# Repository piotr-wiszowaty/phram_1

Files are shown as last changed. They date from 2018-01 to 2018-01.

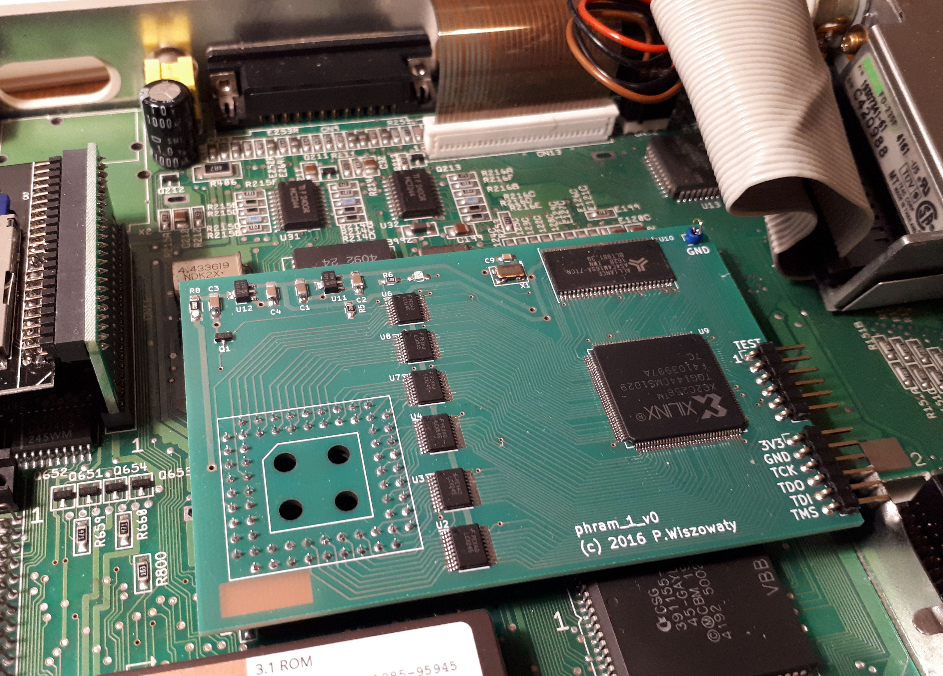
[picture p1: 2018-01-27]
prod/phram_1.jpg

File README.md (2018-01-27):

phram\_1
========

phram\_1 is a Commodore Amiga A600 extension - 8 MB of fast RAM.

Features :
----------

* based on modern parts (CoolRunner CPLD, SDRAM)
* PCMCIA-friendly: holding `reset` for more than 3 seconds turns off high 4 MB
* current consumption around 110 mA
* speedup relative to stock A600: 33 % (by SysInfo)
* successfully tested with CheckMem and MemCheck 1.2 (both available
  on [Aminet](http://aminet.net)).

Sources
-------

`cpld/` - MMU design files (Xilinx ISE 14.7)

`pcb/`  - PCB design files (KiCAD, built 2017-11-24 revision a01d81e4b)

`prod/` - JED, Gerbers and a photo of the expansion; the current PCB
          has some tweaks compared with the device on the photo

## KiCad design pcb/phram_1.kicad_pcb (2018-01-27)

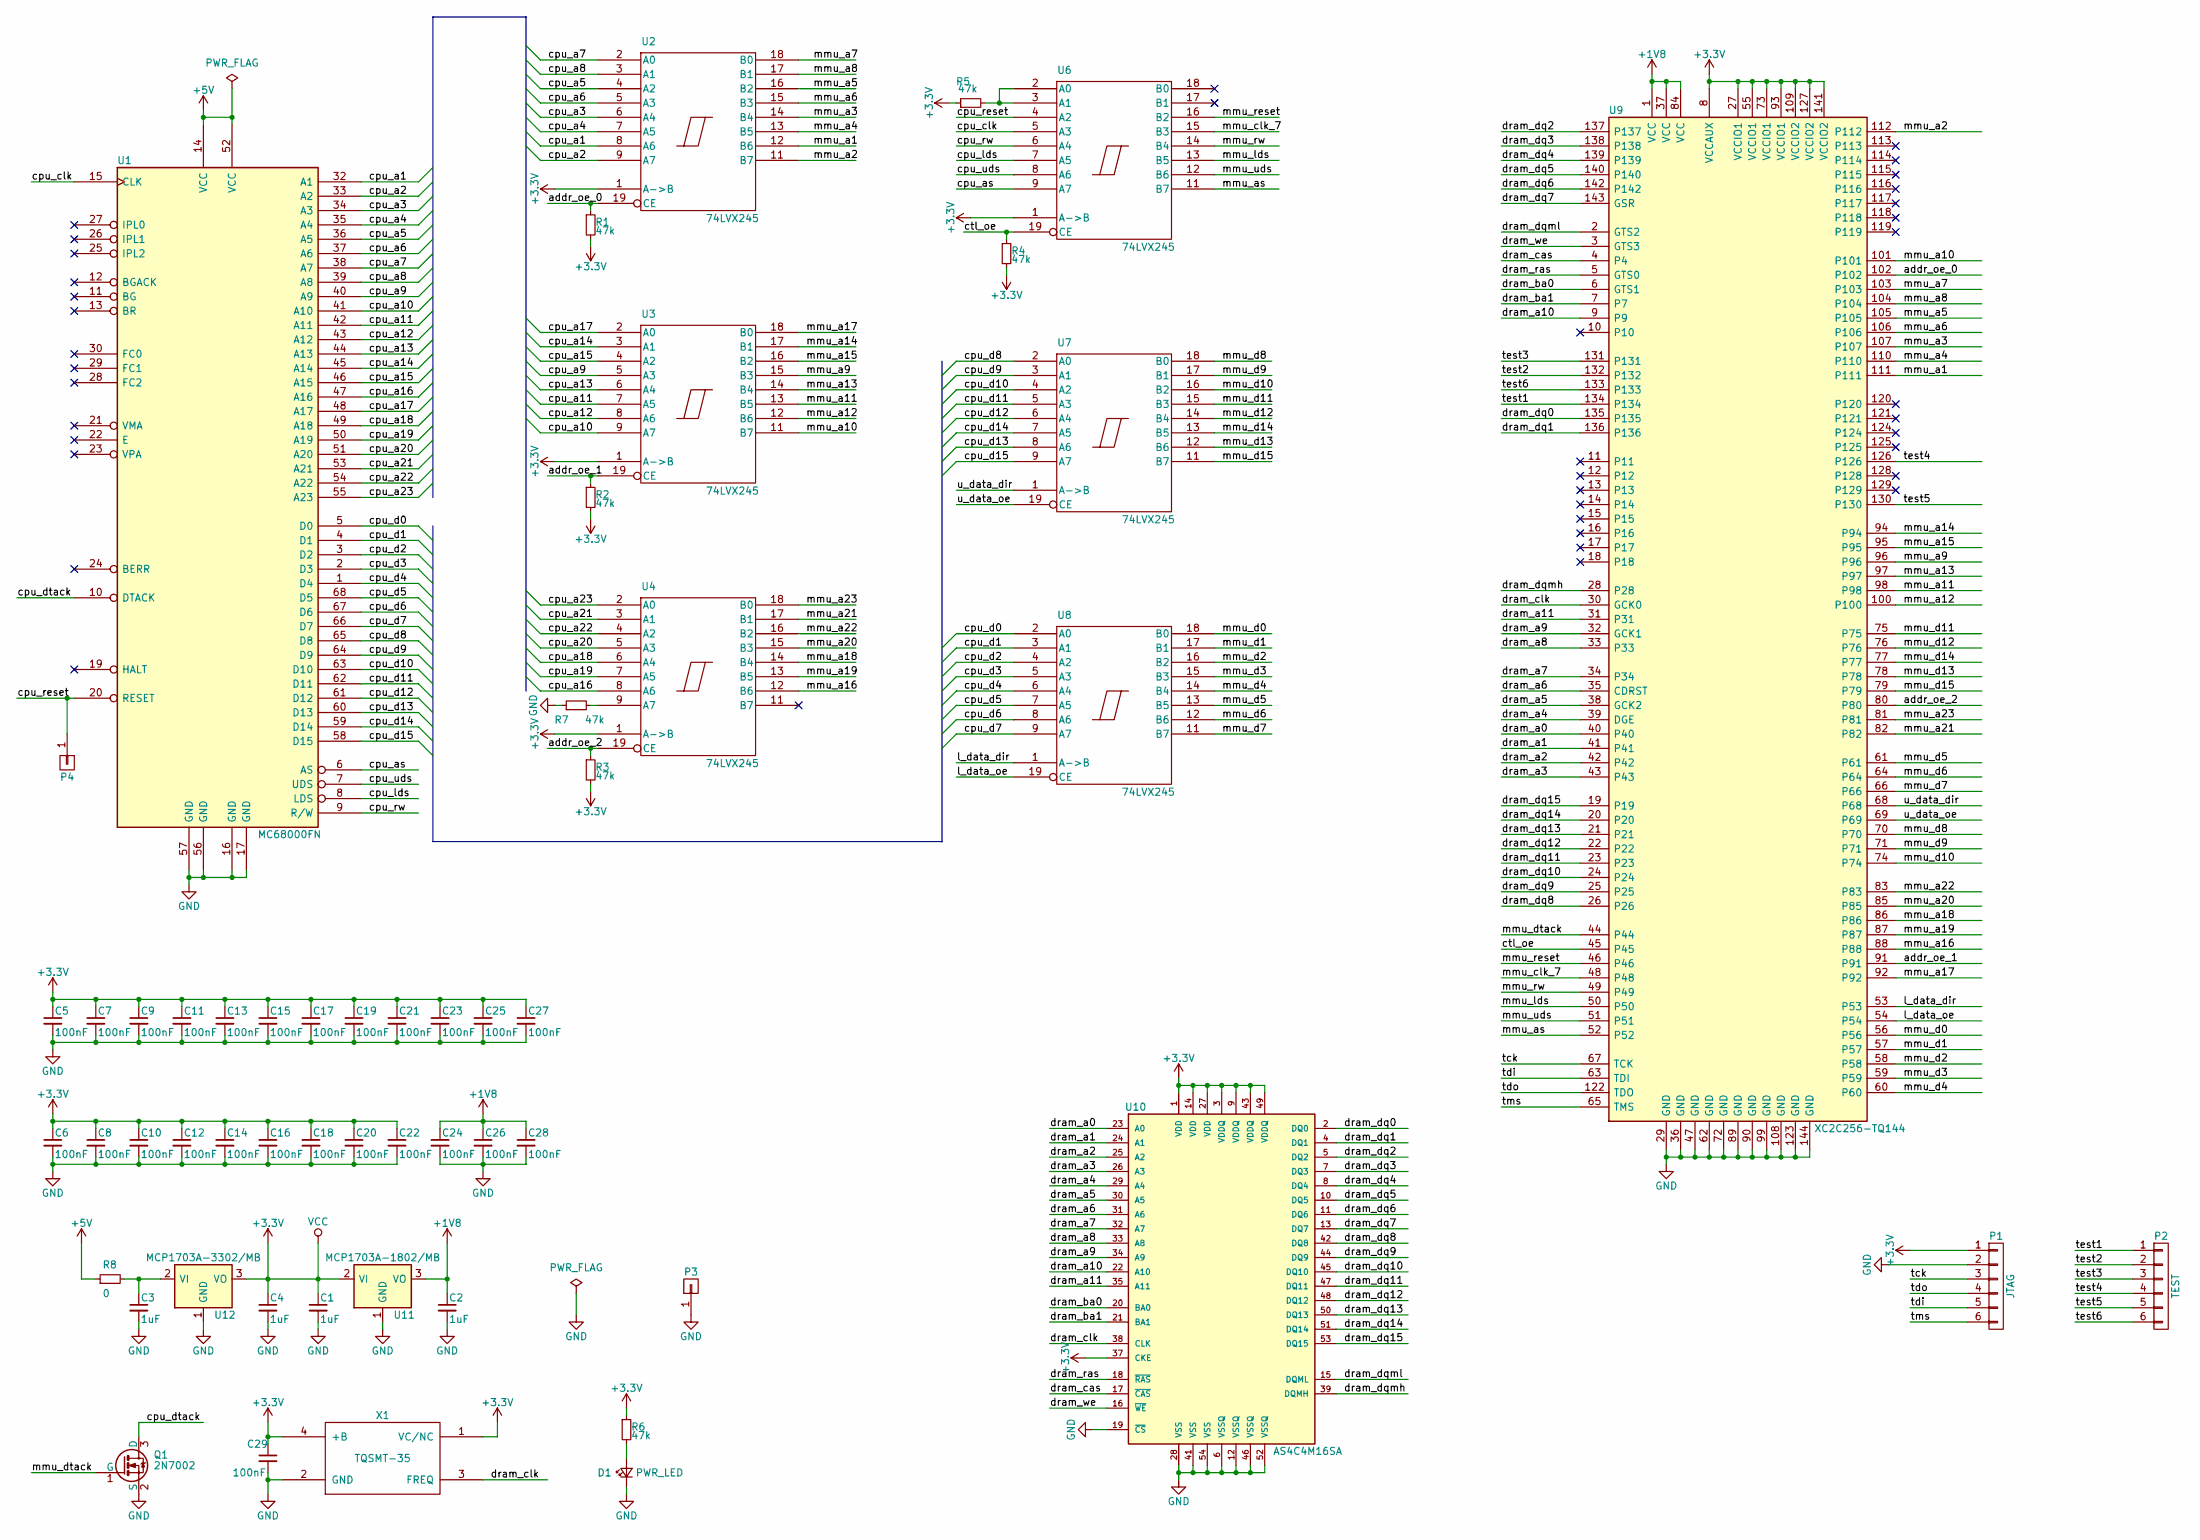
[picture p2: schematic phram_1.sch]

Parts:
C1, C2, C3, C4: 1uF; C_1206_HandSoldering
C5, C6, C7, C8, C9, C10, C11, C12, C13, C14, C15, C16, C17, C18, C19, C20, C21, C22, C23, C24, C25, C26, C27, C28, C29: 100nF; C_0805_HandSoldering
D1: PWR_LED; R_0805_HandSoldering
P1: JTAG; Pin_Header_Angled_1x06
P2: TEST; Pin_Header_Angled_1x06
P3, P4: CONN_01X01; Pin_Header_Straight_1x01
Q1: 2N7002; SOT-23
R1, R2, R3, R4, R5, R6, R7: 47k; R_0805_HandSoldering
R8: 0; R_1206_HandSoldering
U1: MC68000FN; PLCC68-upsidedown
U2, U3, U4, U6, U7, U8: 74LVX245; TSSOP-20_4.4x6.5mm_Pitch0.65mm
U9: XC2C256-TQ144; TQFP-144_20x20mm_Pitch0.5mm
U10: AS4C4M16SA; TSOP-II-54_22.22x10.16mm_Pitch0.8mm
U11: MCP1703A-1802/MB; SOT89-3_Housing
U12: MCP1703A-3302/MB; SOT89-3_Housing
X1: TQSMT-35; IS92

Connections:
+1V8: C2.1, C24.1, C26.1, C28.1, U9.1 (VCC), U9.37 (VCC), U9.84 (VCC), U11.3 (VO)
+3V3: C1.1, C4.1, C5.1, C6.1, C7.1, C8.1, C9.1, C10.1, C11.1, C12.1, C13.1, C14.1, C15.1, C16.1, C17.1, C18.1, C19.1, C20.1, C21.1, C22.1, C23.1, C25.1, C27.1, C29.1, P1.1, R1.2, R2.2, R3.2, R4.2, R5.1, R6.1, U2.1 (A->B), U2.20 (VCC), U3.1 (A->B), U3.20 (VCC), U4.1 (A->B), U4.20 (VCC), U6.1 (A->B), U6.20 (VCC), U7.20 (VCC), U8.20 (VCC), U9.8 (VCCAUX), U9.27 (VCCIO1), U9.55 (VCCIO1), U9.73 (VCCIO1), U9.93 (VCCIO1), U9.109 (VCCIO2), U9.127 (VCCIO2), U9.141 (VCCIO2), U10.1 (VDD), U10.3 (VDDQ), U10.9 (VDDQ), U10.14 (VDD), U10.27 (VDD), U10.37 (CKE), U10.43 (VDDQ), U10.49 (VDDQ), U11.2 (VI), U12.3 (VO), X1.1 (VC/NC), X1.4 (+B)
+5V: R8.1, U1.14 (VCC), U1.52 (VCC)
/addr_oe_0: R1.1, U2.19 (CE), U9.102
/addr_oe_1: R2.1, U3.19 (CE), U9.91
/addr_oe_2: R3.1, U4.19 (CE), U9.80
/cpu_a1: U1.32 (A1), U2.8 (A6)
/cpu_a2: U1.33 (A2), U2.9 (A7)
/cpu_a3: U1.34 (A3), U2.6 (A4)
/cpu_a4: U1.35 (A4), U2.7 (A5)
/cpu_a5: U1.36 (A5), U2.4 (A2)
/cpu_a6: U1.37 (A6), U2.5 (A3)
/cpu_a7: U1.38 (A7), U2.2 (A0)
/cpu_a8: U1.39 (A8), U2.3 (A1)
/cpu_a9: U1.40 (A9), U3.5 (A3)
/cpu_a10: U1.41 (A10), U3.9 (A7)
/cpu_a11: U1.42 (A11), U3.7 (A5)
/cpu_a12: U1.43 (A12), U3.8 (A6)
/cpu_a13: U1.44 (A13), U3.6 (A4)
/cpu_a14: U1.45 (A14), U3.3 (A1)
/cpu_a15: U1.46 (A15), U3.4 (A2)
/cpu_a16: U1.47 (A16), U4.8 (A6)
/cpu_a17: U1.48 (A17), U3.2 (A0)
/cpu_a18: U1.49 (A18), U4.6 (A4)
/cpu_a19: U1.50 (A19), U4.7 (A5)
/cpu_a20: U1.51 (A20), U4.5 (A3)
/cpu_a21: U1.53 (A21), U4.3 (A1)
/cpu_a22: U1.54 (A22), U4.4 (A2)
/cpu_a23: U1.55 (A23), U4.2 (A0)
/cpu_as: U1.6 (AS), U6.9 (A7)
/cpu_clk: U1.15 (CLK), U6.5 (A3)
/cpu_d0: U1.5 (D0), U8.2 (A0)
/cpu_d1: U1.4 (D1), U8.3 (A1)
/cpu_d2: U1.3 (D2), U8.4 (A2)
/cpu_d3: U1.2 (D3), U8.5 (A3)
/cpu_d4: U1.1 (D4), U8.6 (A4)
/cpu_d5: U1.68 (D5), U8.7 (A5)
/cpu_d6: U1.67 (D6), U8.8 (A6)
/cpu_d7: U1.66 (D7), U8.9 (A7)
/cpu_d8: U1.65 (D8), U7.2 (A0)
/cpu_d9: U1.64 (D9), U7.3 (A1)
/cpu_d10: U1.63 (D10), U7.4 (A2)
/cpu_d11: U1.62 (D11), U7.5 (A3)
/cpu_d12: U1.61 (D12), U7.6 (A4)
/cpu_d13: U1.60 (D13), U7.8 (A6)
/cpu_d14: U1.59 (D14), U7.7 (A5)
/cpu_d15: U1.58 (D15), U7.9 (A7)
/cpu_dtack: Q1.3 (D), U1.10 (DTACK)
/cpu_lds: U1.8 (LDS), U6.7 (A5)
/cpu_reset: P4.1, U1.20 (RESET), U6.4 (A2)
/cpu_rw: U1.9 (R/W), U6.6 (A4)
/cpu_uds: U1.7 (UDS), U6.8 (A6)
/ctl_oe: R4.1, U6.19 (CE), U9.45
/dram_a0: U9.40, U10.23 (A0)
/dram_a1: U9.41, U10.24 (A1)
/dram_a2: U9.42, U10.25 (A2)
/dram_a3: U9.43, U10.26 (A3)
/dram_a4: U9.39 (DGE), U10.29 (A4)
/dram_a5: U9.38 (GCK2), U10.30 (A5)
/dram_a6: U9.35 (CDRST), U10.31 (A6)
/dram_a7: U9.34, U10.32 (A7)
/dram_a8: U9.33, U10.33 (A8)
/dram_a9: U9.32 (GCK1), U10.34 (A9)
/dram_a10: U9.9, U10.22 (A10)
/dram_a11: U9.31, U10.35 (A11)
/dram_ba0: U9.6 (GTS1), U10.20 (BA0)
/dram_ba1: U9.7, U10.21 (BA1)
/dram_cas: U9.4, U10.17 (~CAS~)
/dram_clk: U9.30 (GCK0), U10.38 (CLK), X1.3 (FREQ)
/dram_dq0: U9.135, U10.2 (DQ0)
/dram_dq1: U9.136, U10.4 (DQ1)
/dram_dq2: U9.137, U10.5 (DQ2)
/dram_dq3: U9.138, U10.7 (DQ3)
/dram_dq4: U9.139, U10.8 (DQ4)
/dram_dq5: U9.140, U10.10 (DQ5)
/dram_dq6: U9.142, U10.11 (DQ6)
/dram_dq7: U9.143 (GSR), U10.13 (DQ7)
/dram_dq8: U9.26, U10.42 (DQ8)
/dram_dq9: U9.25, U10.44 (DQ9)
/dram_dq10: U9.24, U10.45 (DQ10)
/dram_dq11: U9.23, U10.47 (DQ11)
/dram_dq12: U9.22, U10.48 (DQ12)
/dram_dq13: U9.21, U10.50 (DQ13)
/dram_dq14: U9.20, U10.51 (DQ14)
/dram_dq15: U9.19, U10.53 (DQ15)
/dram_dqmh: U9.28, U10.39 (DQMH)
/dram_dqml: U9.2 (GTS2), U10.15 (DQML)
/dram_ras: U9.5 (GTS0), U10.18 (~RAS~)
/dram_we: U9.3 (GTS3), U10.16 (~WE~)
/l_data_dir: U8.1 (A->B), U9.53
/l_data_oe: U8.19 (CE), U9.54
/mmu_a1: U2.12 (B6), U9.111
/mmu_a2: U2.11 (B7), U9.112
/mmu_a3: U2.14 (B4), U9.107
/mmu_a4: U2.13 (B5), U9.110
/mmu_a5: U2.16 (B2), U9.105
/mmu_a6: U2.15 (B3), U9.106
/mmu_a7: U2.18 (B0), U9.103
/mmu_a8: U2.17 (B1), U9.104
/mmu_a9: U3.15 (B3), U9.96
/mmu_a10: U3.11 (B7), U9.101
/mmu_a11: U3.13 (B5), U9.98
/mmu_a12: U3.12 (B6), U9.100
/mmu_a13: U3.14 (B4), U9.97
/mmu_a14: U3.17 (B1), U9.94
/mmu_a15: U3.16 (B2), U9.95
/mmu_a16: U4.12 (B6), U9.88
/mmu_a17: U3.18 (B0), U9.92
/mmu_a18: U4.14 (B4), U9.86
/mmu_a19: U4.13 (B5), U9.87
/mmu_a20: U4.15 (B3), U9.85
/mmu_a21: U4.17 (B1), U9.82
/mmu_a22: U4.16 (B2), U9.83
/mmu_a23: U4.18 (B0), U9.81
/mmu_as: U6.11 (B7), U9.52
/mmu_clk_7: U6.15 (B3), U9.48
/mmu_d0: U8.18 (B0), U9.56
/mmu_d1: U8.17 (B1), U9.57
/mmu_d2: U8.16 (B2), U9.58
/mmu_d3: U8.15 (B3), U9.59
/mmu_d4: U8.14 (B4), U9.60
/mmu_d5: U8.13 (B5), U9.61
/mmu_d6: U8.12 (B6), U9.64
/mmu_d7: U8.11 (B7), U9.66
/mmu_d8: U7.18 (B0), U9.70
/mmu_d9: U7.17 (B1), U9.71
/mmu_d10: U7.16 (B2), U9.74
/mmu_d11: U7.15 (B3), U9.75
/mmu_d12: U7.14 (B4), U9.76
/mmu_d13: U7.12 (B6), U9.78
/mmu_d14: U7.13 (B5), U9.77
/mmu_d15: U7.11 (B7), U9.79
/mmu_dtack: Q1.1 (G), U9.44
/mmu_lds: U6.13 (B5), U9.50
/mmu_reset: U6.16 (B2), U9.46
/mmu_rw: U6.14 (B4), U9.49
/mmu_uds: U6.12 (B6), U9.51
/tck: P1.3, U9.67 (TCK)
/tdi: P1.5, U9.63 (TDI)
/tdo: P1.4, U9.122 (TDO)
/test1: P2.1, U9.134
/test2: P2.2, U9.132
/test3: P2.3, U9.131
/test4: P2.4, U9.126
/test5: P2.5, U9.130
/test6: P2.6, U9.133
/tms: P1.6, U9.65 (TMS)
/u_data_dir: U7.1 (A->B), U9.68
/u_data_oe: U7.19 (CE), U9.69
GND: C1.2, C2.2, C3.2, C4.2, C5.2, C6.2, C7.2, C8.2, C9.2, C10.2, C11.2, C12.2, C13.2, C14.2, C15.2, C16.2, C17.2, C18.2, C19.2, C20.2, C21.2, C22.2, C23.2, C24.2, C25.2, C26.2, C27.2, C28.2, C29.2, D1.1 (K), P1.2, P3.1, Q1.2 (S), R7.1, U1.16 (GND), U1.17 (GND), U1.56 (GND), U1.57 (GND), U2.10 (GND), U3.10 (GND), U4.10 (GND), U6.10 (GND), U7.10 (GND), U8.10 (GND), U9.29 (GND), U9.36 (GND), U9.47 (GND), U9.62 (GND), U9.72 (GND), U9.89 (GND), U9.90 (GND), U9.99 (GND), U9.108 (GND), U9.123 (GND), U9.144 (GND), U10.6 (VSSQ), U10.12 (VSSQ), U10.19 (~CS~), U10.28 (VSS), U10.41 (VSS), U10.46 (VSSQ), U10.52 (VSSQ), U10.54 (VSS), U11.1 (GND), U12.1 (GND), X1.2 (GND)
unnamed: C3.1, R8.2, U12.2 (VI)
unnamed: D1.2 (A), R6.2
unnamed: R5.2, U6.2 (A0), U6.3 (A1)
unnamed: R7.2, U4.9 (A7)

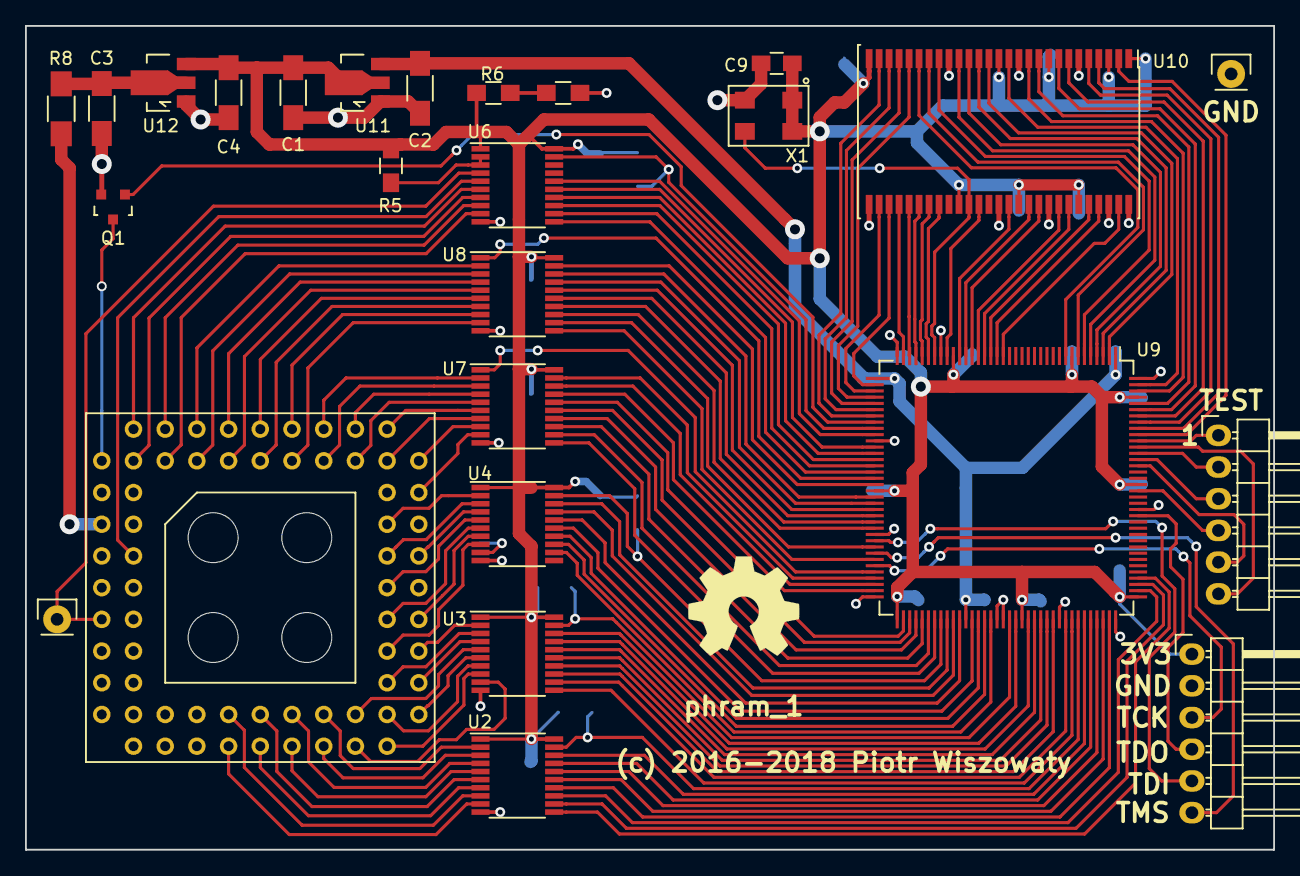
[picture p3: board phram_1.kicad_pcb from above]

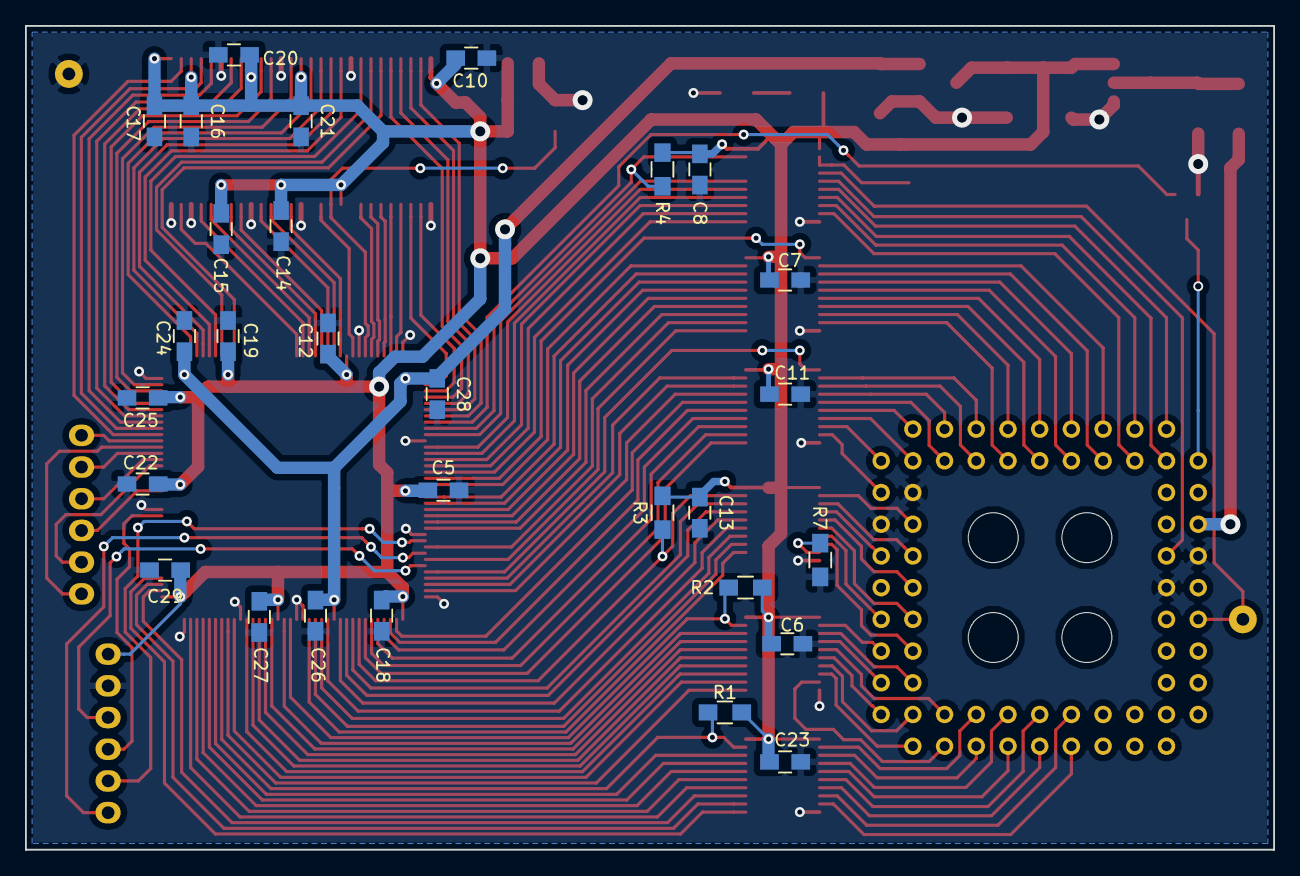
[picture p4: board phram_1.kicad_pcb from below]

Board: 2 copper layers, 100.0 x 66.0 mm, 55 parts (29 on the bottom side), 154 nets.

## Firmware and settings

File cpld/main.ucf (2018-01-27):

NET "dram_clk" TNM = dram_clk;
TIMESPEC TS_clk = PERIOD "dram_clk" 50.0 MHz HIGH 50%;
NET "dram_clk" BUFG = CLK;

NET "mmu_clk_7" TNM = mmu_clk_7;
TIMESPEC TS_ami_clk = PERIOD "mmu_clk_7" 7.2 MHz HIGH 50%;

NET "mmu_data<0>" LOC = p56;
NET "mmu_data<1>" LOC = p57;
NET "mmu_data<2>" LOC = p58;
NET "mmu_data<3>" LOC = p59;
NET "mmu_data<4>" LOC = p60;
NET "mmu_data<5>" LOC = p61;
NET "mmu_data<6>" LOC = p64;
NET "mmu_data<7>" LOC = p66;
NET "mmu_data<8>" LOC = p70;
NET "mmu_data<9>" LOC = p71;
NET "mmu_data<10>" LOC = p74;
NET "mmu_data<11>" LOC = p75;
NET "mmu_data<12>" LOC = p76;
NET "mmu_data<13>" LOC = p78;
NET "mmu_data<14>" LOC = p77;
NET "mmu_data<15>" LOC = p79;
NET "mmu_addr<1>" LOC = p111;
NET "mmu_addr<2>" LOC = p112;
NET "mmu_addr<3>" LOC = p107;
NET "mmu_addr<4>" LOC = p110;
NET "mmu_addr<5>" LOC = p105;
NET "mmu_addr<6>" LOC = p106;
NET "mmu_addr<7>" LOC = p103;
NET "mmu_addr<8>" LOC = p104;
NET "mmu_addr<9>" LOC = p96;
NET "mmu_addr<10>" LOC = p101;
NET "mmu_addr<11>" LOC = p98;
NET "mmu_addr<12>" LOC = p100;
NET "mmu_addr<13>" LOC = p97;
NET "mmu_addr<14>" LOC = p94;
NET "mmu_addr<15>" LOC = p95;
NET "mmu_addr<16>" LOC = p88;
NET "mmu_addr<17>" LOC = p92;
NET "mmu_addr<18>" LOC = p86;
NET "mmu_addr<19>" LOC = p87;
NET "mmu_addr<20>" LOC = p85;
NET "mmu_addr<21>" LOC = p82;
NET "mmu_addr<22>" LOC = p83;
NET "mmu_addr<23>" LOC = p81;

NET "mmu_dtack" LOC = p44;
NET "mmu_reset" LOC = p46;
NET "mmu_clk_7" LOC = p48;
NET "mmu_rw" LOC = p49;
NET "mmu_lds" LOC = p50;
NET "mmu_uds" LOC = p51;
NET "mmu_as" LOC = p52;

NET "ctl_oe" LOC = p45;
NET "l_data_oe" LOC = p54;
NET "u_data_oe" LOC = p69;
NET "l_data_dir" LOC = p53;
NET "u_data_dir" LOC = p68;
NET "addr_oe_0" LOC = p102;
NET "addr_oe_1" LOC = p91;
NET "addr_oe_2" LOC = p80;

NET "dram_addr<0>" LOC = p40;
NET "dram_addr<1>" LOC = p41;
NET "dram_addr<2>" LOC = p42;
NET "dram_addr<3>" LOC = p43;
NET "dram_addr<4>" LOC = p39;
NET "dram_addr<5>" LOC = p38;
NET "dram_addr<6>" LOC = p35;
NET "dram_addr<7>" LOC = p34;
NET "dram_addr<8>" LOC = p33;
NET "dram_addr<9>" LOC = p32;
NET "dram_addr<10>" LOC = p9;
NET "dram_addr<11>" LOC = p31;
NET "dram_dq<0>" LOC = p135;
NET "dram_dq<1>" LOC = p136;
NET "dram_dq<2>" LOC = p137;
NET "dram_dq<3>" LOC = p138;
NET "dram_dq<4>" LOC = p139;
NET "dram_dq<5>" LOC = p140;
NET "dram_dq<6>" LOC = p142;
NET "dram_dq<7>" LOC = p143;
NET "dram_dq<8>" LOC = p26;
NET "dram_dq<9>" LOC = p25;
NET "dram_dq<10>" LOC = p24;
NET "dram_dq<11>" LOC = p23;
NET "dram_dq<12>" LOC = p22;
NET "dram_dq<13>" LOC = p21;
NET "dram_dq<14>" LOC = p20;
NET "dram_dq<15>" LOC = p19;
NET "dram_ba<0>" LOC = p6;
NET "dram_ba<1>" LOC = p7;
NET "dram_dqml" LOC = p2;
NET "dram_dqmh" LOC = p28;
NET "dram_ras_n" LOC = p5;
NET "dram_cas_n" LOC = p4;
NET "dram_we_n" LOC = p3;
NET "dram_clk" LOC = p30;

NET "test<1>" LOC = p134;
NET "test<2>" LOC = p132;
NET "test<3>" LOC = p131;
NET "test<4>" LOC = p126;
NET "test<5>" LOC = p130;
NET "test<6>" LOC = p133;

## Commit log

2018-01-27 Add CPLD and PCB design files, update README
    [phram_1.kicad_pcb, phram_1.sch]
2018-01-27 Add JED, Gerbers and a photo
    [phram_1-B.Cu.gbr, phram_1-B.Mask.gbr, phram_1-B.SilkS.gbr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]

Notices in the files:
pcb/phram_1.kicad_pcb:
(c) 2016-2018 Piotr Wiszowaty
